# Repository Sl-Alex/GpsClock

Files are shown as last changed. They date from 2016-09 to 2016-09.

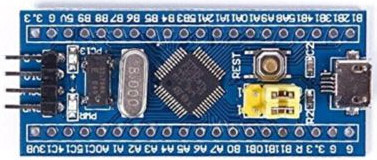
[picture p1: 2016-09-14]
modules/stm32f103c8t6_board.jpg

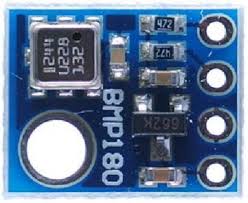
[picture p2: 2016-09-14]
modules/bmp180_module.jpg

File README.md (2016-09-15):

#LED matrix GPS wall clock

This project has the following features:
- 80x24 big LED matrix display with automatic brightness control (based on HT16K33 drivers).
- Temperature/humidity measurement.
- Air pressure monitoring/logging. Last 24 hours are always on the display in a form of a diagram.
- Non-volatile FRAM memory for the air pressure log.
- GPS module for automatic time synchronization.
- No buttons, no settings. User manual is not required.
- Automatic DST time correction. Time zone can be easily changed in the source code, no further modifications are required.

Following 3rd party HW was used:
- STM32F103C8T6 minimum system development board ([photo](./modules/stm32f103c8t6_board.jpg))
- BMP180 temperature/pressure sensor module ([photo](./modules/bmp180_module.jpg))
- BH1750 light sensor  module ([photo](./modules/bh1750_module.jpg))
- Si7021 temperature/humidity sensor  module ([photo](./modules/si7021_module.jpg))
- FM24C04 FRAM chip.
- EB-800 GPS module with 5V->3V converter.

Module interconnections are available on [this](./schematic.png) diagram. The only PCB you have to make is a HT16K33 module (15 pcs). KiCAD project is in the [PCB](./PCB) folder.

P.S. If 32kHz generation on the processor board is not stable, then it is highly recommended to make a proper crystal grounding.

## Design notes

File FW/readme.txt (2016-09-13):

This project aims to create automatic clock, which uses GPS module to synchronize local time.
Also it has automatic DST control.

License information
The whole project except of parts from a 3rd party vendor (see below) is licensed
under GPL v3 license. License information is located in "license.txt" file.

Project uses the following source code from 3rd party vendors:
    - CMSIS headers by ARM Limited (http://www.arm.com/)
    - FreeRTOS operating system by Real Time Engineers Ltd (http://www.freertos.org/);
    - CMSIS and peripheral library by STMicroelectronics (http://www.st.com/);

For licensing information please refer to the appropriate source code files.
    - CMSIS headers are located in "CMSIS" folder
    - FreeRTOS distribution is located in "FreeRTOS" folder
    - Peripheral library is located in "SPL" folder

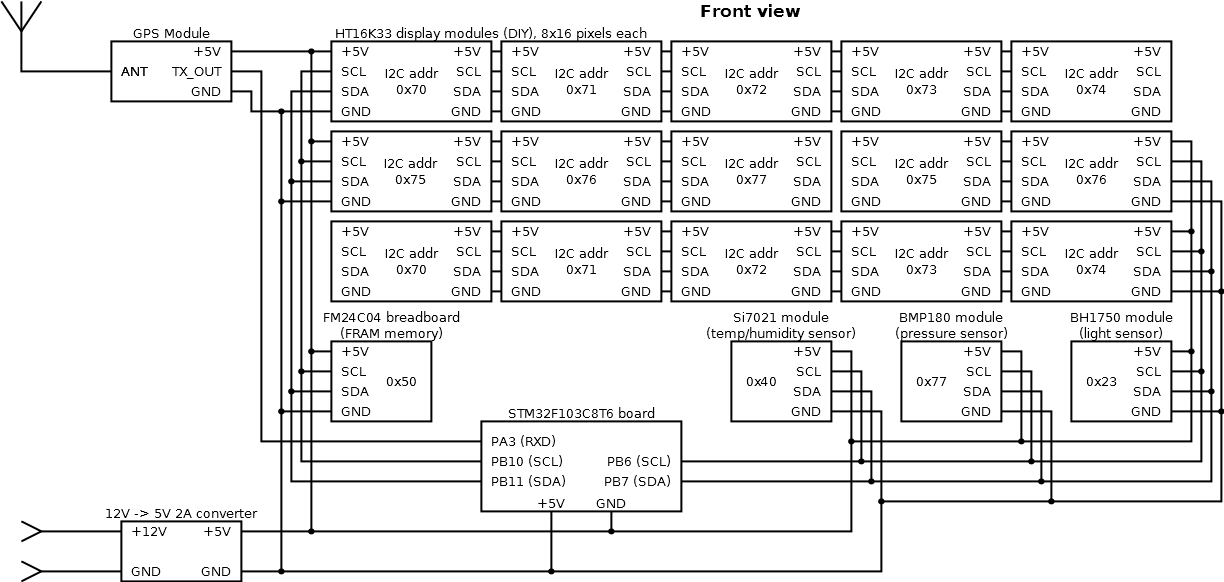
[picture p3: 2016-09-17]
schematic.png

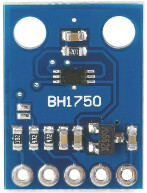
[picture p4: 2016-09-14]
modules/bh1750_module.jpg

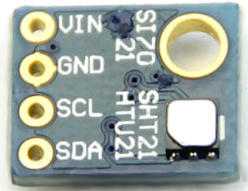
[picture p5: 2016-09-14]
modules/si7021_module.jpg

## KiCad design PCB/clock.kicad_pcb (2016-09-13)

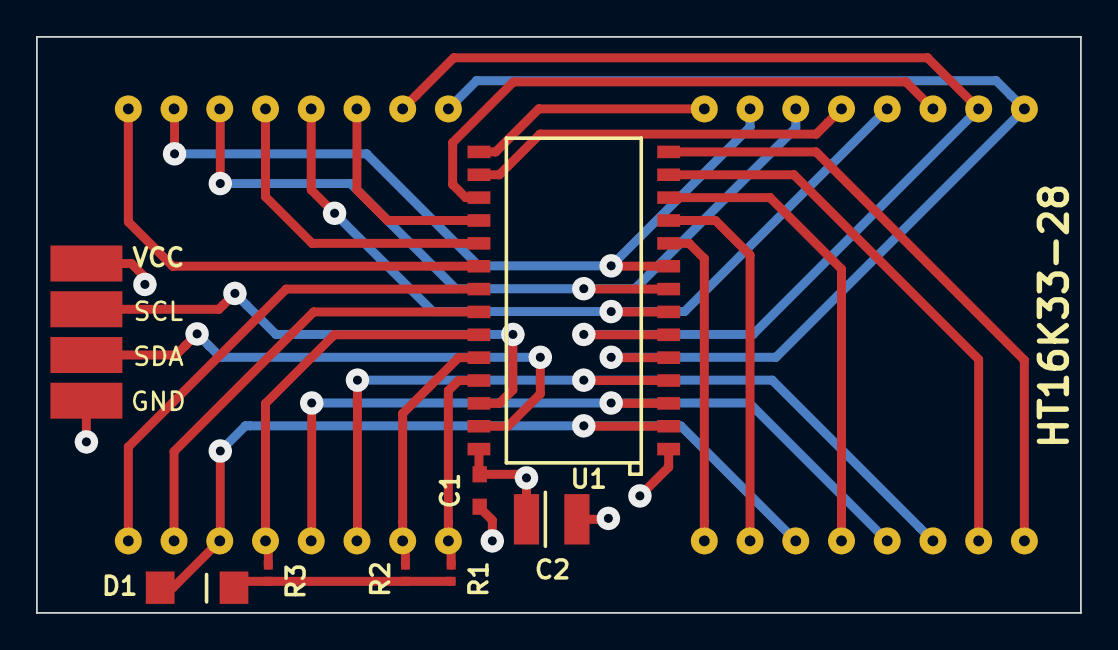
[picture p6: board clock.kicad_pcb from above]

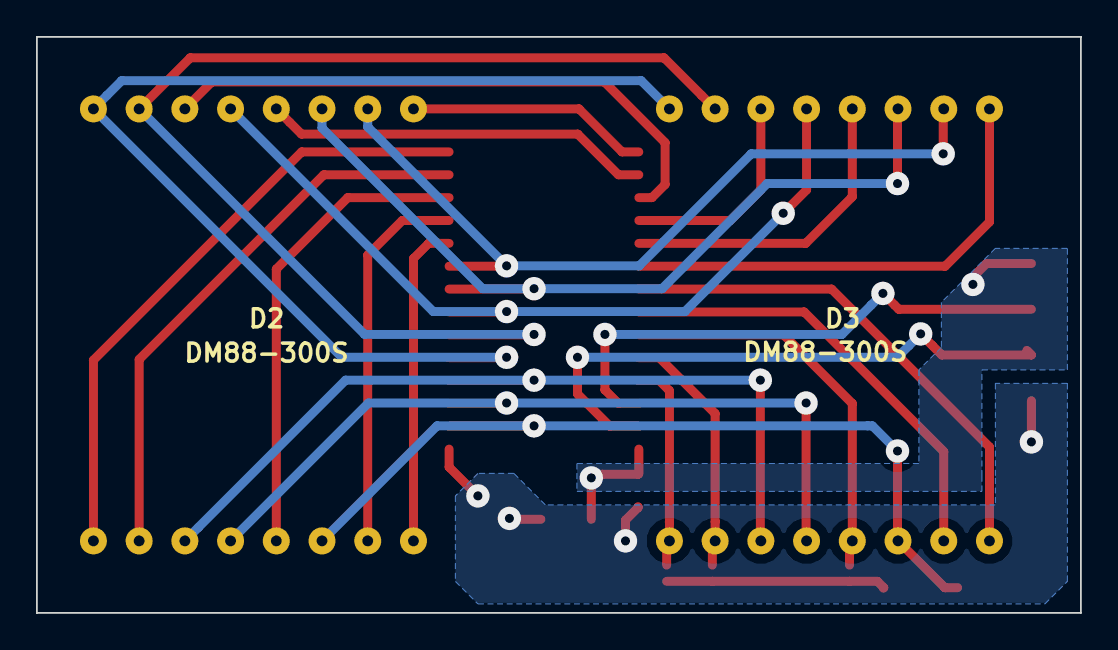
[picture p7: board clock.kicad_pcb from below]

Board: 2 copper layers, 58.0 x 32.0 mm, 13 parts (2 on the bottom side), 29 nets.

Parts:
C1: capacitor; 0603_C
C2: capacitor_el; case_B
D1: diode; SOD-80
D2, D3: DM88-300S
R1, R2, R3: resistor; 0402_R
U1: HT16K33-28; SO28
X1: VCC; PLS1_SMD
X2: GND; PLS1_SMD
X3: SCL; PLS1_SMD
X4: SDA; PLS1_SMD

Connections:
/COL0: D1.1, D2.14, D3.14, U1.2
/COL1: D2.12, D3.12, U1.3
/COL2: D2.11, D3.11, U1.4
/COL3: D2.8, D3.8, U1.5
/COL4: D2.7, D3.7, U1.6
/COL5: D2.5, D3.5, U1.7
/COL6: D2.3, D3.3, U1.8
/COL7: D2.2, D3.2, U1.9
/ROW0: D3.9, R1.1, U1.25
/ROW1: D3.10, R2.1, U1.24
/ROW2: D3.13, R3.1, U1.23
/ROW3: D3.15, U1.22
/ROW4: D3.16, U1.21
/ROW5: D3.1, U1.20
/ROW6: D3.4, U1.19
/ROW7: D3.6, U1.18
/ROW8: D2.6, U1.17
/ROW9: D2.4, U1.16
/ROW10: D2.1, U1.15
/ROW11: D2.9, U1.14
/ROW12: D2.10, U1.13
/ROW13: D2.13, U1.12
/ROW14: D2.15, U1.11
/ROW15: D2.16, U1.10
/SCL: U1.26, X3.1
/SDA: U1.27, X4.1
/VCC: C1.1, C2.1, U1.28, X1.1
GND: C1.2, C2.2, U1.1, X2.1
unnamed: D1.2, R1.2, R2.2, R3.2

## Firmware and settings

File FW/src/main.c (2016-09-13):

/*
    This file is part of "GPS clock" project.

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
    Some parts of this project are written by 3-rd party vendors under a
    different license. See readme.txt for the complete list of 3-rd party
    source code.

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
    You should have received a copy of the GNU General Public License
    along with "GPS clock".  If not, see <http://www.gnu.org/licenses/>.
*/

/**
* @file usr_nmea_parser.c
* @brief NMEA parser. Gets date/time (UTC), satellites information
*
* @author Oleksii Slabchenko, alexslabchenko@gmail.com
*/

/**
* @mainpage
*
* @section brief_sec Brief description
*
* This project aims to create automatic clock, which uses GPS module to synchronize local time.
* Also it has automatic DST control
*
* @section license_sec License information
* The whole project except of parts from a 3<sup>rd</sup> party vendor (see below) is licensed
* under GPL v3 license. License information is located in "license.txt" file.
*
* Project uses the following source code from 3<sup>rd</sup> party vendors:
*   - CMSIS headers by ARM Limited (http://www.arm.com/)
*   - FreeRTOS operating system by Real Time Engineers Ltd (http://www.freertos.org/);
*   - CMSIS and peripheral library by STMicroelectronics (http://www.st.com/);
*
* For licensing information please refer to the appropriate source code files.
*   - CMSIS headers are located in "CMSIS" folder
*   - FreeRTOS distribution is located in "FreeRTOS" folder
*   - Peripheral library is located in "SPL" folder
*
* @section SEC_OTHER Changing firmware
*
* @note If you want to change time zone, you should modify @ref usr_rtc_get_local_time
* function. Currently time zone is set to UTC+2 (EET), DST is used.
*
* @note If you want to localize firmware, you should modify @ref usr_font variable.
* It contains complete one-byte code page, such as 1251 (Cyrillic). You are free to implement
* your own set of symbols. If you need pseudo-graphic - you can use, for example, symbols
* from 0x01 to 0x1F or (at you own risk) any other. Symbol 0x00 should not be used because
* all strings are null-terminated.<br />
* All text messages are contained in @ref usr_messages.c file. If you want to change these
* messages - please pay attention that this file must be saved in the same one-byte code page,
* as implemented in usr_font.c<br />
* As an additional good thing you should change <b>INPUT_ENCODING</b> parameter according to
* your code page, thus all Doxygen-generated documentation will be readable.
*
* @todo (Sl-Alex#99#) Write about manual brightness curve modification
*
* @copyright Oleksii Slabchenko, 2014
*/
#include "stm32f10x_conf.h"
#include "stm32f10x.h"
#include "stm32f10x_rcc.h"
#include "stm32f10x_usart.h"
#include "usr_time_utils.h"

#include "FreeRTOS.h"
#include "task.h"
#include "queue.h"
#include "string.h"
#include "stdlib.h"
#include "stdio.h"

#include "usr_global.h"

#include "usr_error.h"
#include "usr_ht16k33.h"
#include "usr_tasks.h"

int main(void)
{

    SystemCoreClockUpdate();
    NVIC_PriorityGroupConfig( NVIC_PriorityGroup_4 );

    // Queue for UART reception
    xQueueNMEA = xQueueCreate(32, sizeof(uint8_t));
    if (xQueueNMEA == 0)
        usr_error(__FILE__, __LINE__, "NMEA rx queue creation failed\n");
    // Queue for detected UTC time
    xQueueClock = xQueueCreate (10, sizeof(TIME_T));
    if (xQueueClock == 0)
        usr_error(__FILE__, __LINE__, "Clock queue creation failed\n");
    if(pdTRUE != xTaskCreate( vTaskNMEA, ( const char * ) "NMEA Decoder", configMINIMAL_STACK_SIZE*3, NULL, tskIDLE_PRIORITY + 1, NULL))
        usr_error(__FILE__, __LINE__, "NMEA task start failure\n");
    if(pdTRUE != xTaskCreate( vTaskDisplay, ( const char * ) "Clock", configMINIMAL_STACK_SIZE*3, NULL, tskIDLE_PRIORITY + 1, NULL))
        usr_error(__FILE__, __LINE__, "Clock task start failure\n");

    vTasksInit();

    vTaskStartScheduler();

    usr_error(__FILE__, __LINE__, "Scheduler start failure\n");
    while(1); // <- Should never be here
}

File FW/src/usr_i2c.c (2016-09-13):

/*
    This file is part of "GPS clock" project.

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
    Some parts of this project are written by 3-rd party vendors under a
    different license. See readme.txt for the complete list of 3-rd party
    source code.

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
    You should have received a copy of the GNU General Public License
    along with "GPS clock".  If not, see <http://www.gnu.org/licenses/>.
*/

/**
* @file usr_i2c.c
* @brief i2c functionality
* @author Oleksii Slabchenko, alexslabchenko@gmail.com
* @copyright Oleksii Slabchenko, 2014
*/

#include "usr_i2c.h"
#include "FreeRTOS.h"
#include "task.h"

///@brief Actual timeout can be one tick longer
#define I2C_TIMEOUT         7
#define I2C_RETRANSMISSION  3

void usr_i2c_init(void)
{
    I2C_InitTypeDef  I2C_InitStructure;
    GPIO_InitTypeDef  GPIO_InitStructure;

    // Enable peripheral clock for I2C1, I2C2, GPIOB and AFIO
    RCC_APB1PeriphClockCmd(RCC_APB1Periph_I2C1  | RCC_APB1Periph_I2C2, ENABLE);
    RCC_APB2PeriphClockCmd(RCC_APB2Periph_GPIOB | RCC_APB2Periph_AFIO, ENABLE);//

    // Configure I2C1 pins: PB6->SCL  and PB7->SDA
    // Configure I2C2 pins: PB10->SCL and PB11->SDA
    GPIO_InitStructure.GPIO_Pin =  GPIO_Pin_6  | GPIO_Pin_7 |
                                   GPIO_Pin_10 | GPIO_Pin_11;
    GPIO_InitStructure.GPIO_Speed = GPIO_Speed_50MHz;
    GPIO_InitStructure.GPIO_Mode = GPIO_Mode_AF_OD;
    GPIO_Init(GPIOB, &GPIO_InitStructure);

    // Deinit I2C1 and I2C2
    I2C_DeInit(I2C1);
    I2C_DeInit(I2C2);

    // Prepare I2C configuration for both i2c channels
    /// @todo (Sl-Alex#1#) Update i2c clock to 400k
    I2C_InitStructure.I2C_Mode = I2C_Mode_I2C;
    I2C_InitStructure.I2C_DutyCycle = I2C_DutyCycle_2;
    I2C_InitStructure.I2C_OwnAddress1 = 1;
    I2C_InitStructure.I2C_Ack = I2C_Ack_Enable;
    I2C_InitStructure.I2C_AcknowledgedAddress = I2C_AcknowledgedAddress_7bit;
    I2C_InitStructure.I2C_ClockSpeed = 100000;  /* 100kHz */

    // Configure I2C1
    I2C_Cmd(I2C1, ENABLE);
    I2C_Init(I2C1, &I2C_InitStructure);
    I2C_AcknowledgeConfig(I2C1, ENABLE);

    // Configure I2C2
    I2C_Cmd(I2C2, ENABLE);
    I2C_Init(I2C2, &I2C_InitStructure);
    I2C_AcknowledgeConfig(I2C2, ENABLE);
}

uint32_t usr_i2c_stop(I2C_TypeDef * interface)
{
    TickType_t xLastWakeTime;
    // Generate STOP condition
    I2C_GenerateSTOP(interface, ENABLE);
    xLastWakeTime = xTaskGetTickCount ();
    while(xTaskGetTickCount() <= (xLastWakeTime + I2C_TIMEOUT))
    {
        if (I2C_GetFlagStatus(interface, I2C_FLAG_BUSY) == RESET)
        {
            return 1;
        }
    }
    // Failed, send STOP condition
    return 0;
}

uint32_t usr_i2c_start(I2C_TypeDef * interface)
{
    TickType_t xLastWakeTime;
    //vTaskDelay(1);
    I2C_GenerateSTART(interface, ENABLE);
    xLastWakeTime = xTaskGetTickCount ();
    while(xTaskGetTickCount() <= (xLastWakeTime + I2C_TIMEOUT))
    {
        if (I2C_CheckEvent(interface, I2C_EVENT_MASTER_MODE_SELECT) != 0)
        {
            return 1;
        }
    }
    // Failed, send STOP condition
    usr_i2c_stop(interface);
    return 0;
}

uint32_t usr_i2c_send_addr_rd(I2C_TypeDef * interface, uint8_t addr)
{
    TickType_t xLastWakeTime;
    /* Send dev_addr for read */
    I2C_Send7bitAddress(interface, addr << 1, I2C_Direction_Receiver);
    xLastWakeTime = xTaskGetTickCount ();
    while(xTaskGetTickCount() <= (xLastWakeTime + I2C_TIMEOUT))
    {
        if (I2C_CheckEvent(interface, I2C_EVENT_MASTER_RECEIVER_MODE_SELECTED) != 0)
        {
            return 1;
        }
    }
    // Failed, send STOP condition
    usr_i2c_stop(interface);
    return 0;
}

uint32_t usr_i2c_send_addr_wr(I2C_TypeDef * interface, uint8_t addr)
{
    TickType_t xLastWakeTime;
    /* Send dev_addr for read */
    I2C_Send7bitAddress(interface, addr << 1, I2C_Direction_Transmitter);
    xLastWakeTime = xTaskGetTickCount ();
    while(xTaskGetTickCount() <= (xLastWakeTime + I2C_TIMEOUT))
    {
        if (I2C_CheckEvent(interface, I2C_EVENT_MASTER_TRANSMITTER_MODE_SELECTED) != 0)
        {
            return 1;
        }
    }
    // Failed, send STOP condition
    usr_i2c_stop(interface);
    return 0;
}

uint32_t usr_i2c_writedata(I2C_TypeDef * interface, uint8_t * data, uint8_t datasize)
{
    TickType_t xLastWakeTime;
    uint8_t tx_done;

    for (uint8_t i = 0; i < datasize; i++)
    {
        // Write byte
        I2C_SendData(interface, data[i]);
        xLastWakeTime = xTaskGetTickCount ();
        tx_done = 0;
        while(xTaskGetTickCount() <= (xLastWakeTime + I2C_TIMEOUT))
        {
            if (I2C_CheckEvent(interface, I2C_EVENT_MASTER_BYTE_TRANSMITTED) != 0)
            {
                tx_done = 1;
                break;
            }
        }

        if (tx_done != 0)
            continue;

        /* Send STOP condition */
        usr_i2c_stop(interface);
        return 0;
    }
    return datasize;
}
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

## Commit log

2016-09-13 First public revision of LED matrix driver PCB
    [clock-B_Cu.gbl, clock-B_Mask.gbs, clock-B_Paste.gbp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]
2016-09-17 Minor schematic correction

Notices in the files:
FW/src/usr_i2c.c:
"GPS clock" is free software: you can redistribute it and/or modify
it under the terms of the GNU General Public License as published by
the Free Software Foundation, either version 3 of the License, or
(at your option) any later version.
